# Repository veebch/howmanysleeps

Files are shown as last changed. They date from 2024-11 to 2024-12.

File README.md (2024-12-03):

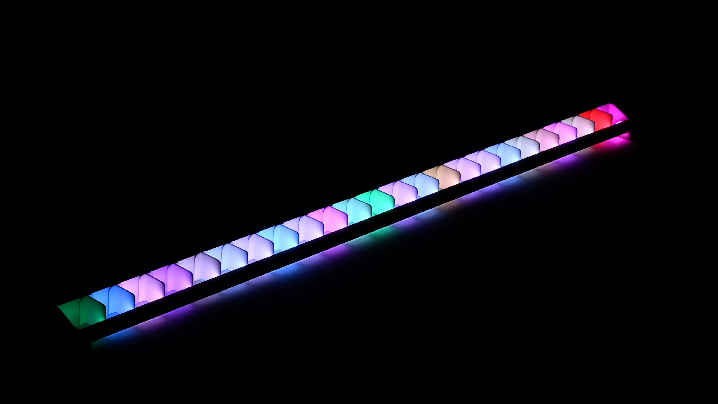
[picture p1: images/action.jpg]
Action Shot


 

# How Many Sleeps?

An Advent Calendar progress-bar decoration that uses a Raspberry Pi Pico W (2) to show you how many sleeps until Christmas (during Advent). It has
a light dependent resistor (LDR) to make the lights only turn on when it is dark and an override button so that you can turn 
the lights off at bedtime. 

Outside of advent, it acts as an automatic light, which is also pretty.

## Assembly

### Components

#### Electronics 

- Rasperry Pi Pico 2W (it is compatible with the original W too)
- 1m 144 LED neopixel strip (We used a WS2812 B Eco)
- Momentary Switch
- Light Dependent Resistor (LDR)

#### Enclosure
 
- Prototype board
- 1m L shaped metal strip
- 1m wooden strip (rectangular cross section) 
- 23 separator fins and two end pieces (all in [/3d](3d) directory)

## Build Video

A whizz through the build process:

YouTube (https://www.youtube.com/watch?v=zQKZN75o05Y)

## Wiring

The LDR and the momentary switch both go to GND from GPIO 26 and 15 respectively. 
The NeoPixel strip is connected to GPIO 19 (as well as VSYS and GND)

## Software

Copy the file main.py onto your Pico using whatever method you find easiest. For this single file, it is probably quickest just to use Thonny. Put your WiFi details into the code and that should be it!

## Operation

At dusk (the LDR value can be adjusted in the code if needed) the lights turn on. If it is currently Advent, then the bar acts as a progress bar, charting the number of sleeps until Christmas.
Outside of advent, the light will be a 'breathing' pattern.

Pressing the momentary switch will disable the lights until it gets light again. When it gets bright again, the Pico will reset.

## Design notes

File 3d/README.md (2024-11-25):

# Light Separators

For the 144 LED strip, you will need to print 23 of these to stop ligth leak between days (6 LEDs each)

# End pieces

These may need to be adjusted based on your metal and wood strips

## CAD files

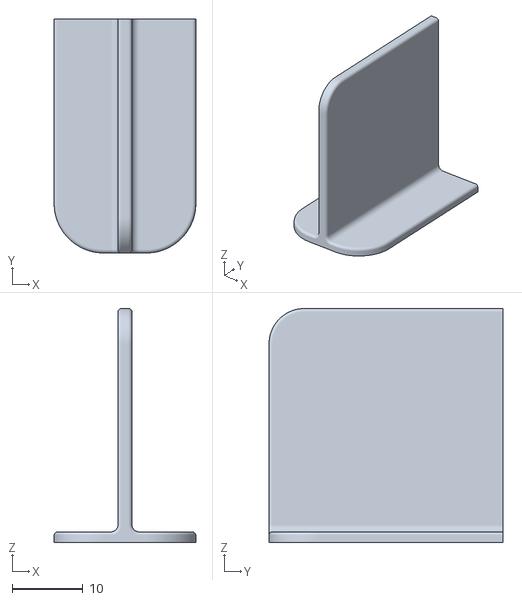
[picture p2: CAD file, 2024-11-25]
3d/barlink.stl
20.0 x 33.0 x 33.0

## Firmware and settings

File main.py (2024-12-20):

import network
import urequests
import time
from machine import Pin, ADC, reset
import neopixel
import random
import math

# Globals
# WiFi credentials
SSID = 'whyayefi'
PASSWORD = 'dizzyflower278'
PIXELS = 144

# Pin Assignment
ldr = ADC(26)  # LDR connected to ADC on GPIO 26
switch = Pin(15, Pin.IN, Pin.PULL_UP)  # Pull-up for momentary switch
np = neopixel.NeoPixel(Pin(19), PIXELS)
led = Pin("LED", Pin.OUT)


def trigger_bedtime(pin):
    global bedtime, np
    switch.irq(handler=None)  # Disable the interrupt after the first trigger we want the button to work once only per day
    print("Interrupt disabled")
    bedtime = True
    print('lights out')


# Function to connect to WiFi
def connect_to_wifi(ssid, password):
    wlan = network.WLAN(network.STA_IF)
    wlan.active(True)
    wlan.connect(ssid, password)
    while not wlan.isconnected():
        print("Connecting to WiFi...")
        time.sleep(1)
    print("Connected to WiFi:", wlan.ifconfig())


# Function to get timezone using ip-api.com
def get_timezone():
    url = "http://ipwhois.app/json/"
    try:
        print("Fetching timezone from IP...")
        response = urequests.get(url)
        if response.status_code == 200:
            data = response.json()
            timezone = data.get('timezone', None)
            response.close()
            if timezone:
                print(f"Detected timezone: {timezone}")
                return timezone
            else:
                print("Timezone not found in response.")
                return None
        else:
            print(f"Error fetching timezone: {response.status_code}")
            response.close()
            return None
    except Exception as e:
        print("Error retrieving timezone:", e)
        return None

# Function to get local time using timeapi.io
def get_local_time(timezone):
    url = f"https://timeapi.io/api/Time/current/zone?timeZone={timezone}"
    try:
        print(f"Fetching local time for timezone: {timezone}")
        response = urequests.get(url)
        if response.status_code == 200:
            data = response.json()
            # Extract year, month, day directly from the JSON response
            year = data['year']
            month = data['month']
            day = data['day']
            response.close()
            return (year, month, day)
        else:
            print(f"Error fetching local time: {response.status_code}")
            response.close()
            return None
    except Exception as e:
        print("Error retrieving local time:", e)
        return None



# Calculate sleeps until Christmas
def sleeps_until_christmas(current_date):
    current_year = current_date[0]
    christmas_date = (current_year, 12, 25)
    christmas_struct = time.mktime(christmas_date + (0, 0, 0, 0, 0))
    today_struct = time.mktime(current_date + (0, 0, 0, 0, 0))
    sleeps = (christmas_struct - today_struct) // 86400 # seconds in a day
    return int(sleeps)


def clamp(value, min_val=0, max_val=255):
    # Clamp a value between min_val and max_val.
    return max(min(int(value), max_val), min_val)

def progress(np,sleeps, spread, howdark):
    advent = sleeps <= 24
    brightfactor=min(int(255*400/(2*(howdark+1))),255)
    print(brightfactor)
    if advent:
        # Advent adjustment to progress bar
        # to make things confusing, LEDs are indexed from (PIXELS-1) to 0
        for i in range(24, sleeps-1, -1):
                variation_1 = (25-i) * random.choice ([-1,1]) #either -1 or +1, each sleep less is more volatile
                variation_2 = (25-i) * random.choice ([-1,1])
                pixelblockchunk = int(PIXELS/24) # We'll use blocks of this size for the first 23 days
                pixelblockmax = PIXELS - (24 - i) * pixelblockchunk
                if i>1:
                    pixelblockmin = pixelblockmax - pixelblockchunk
                else:
                    pixelblockmin = 0
                    # For Christmas Eve, use all remaining pixels
                #print(f'Day: {i}. {pixelblockmin} to {pixelblockmax}')
                for j in range(pixelblockmin,pixelblockmax):
                # Each block drifts at random, clamped between 0 and 255
                    r, g, b = np[j]  # The current RGB values of the pixel
                    r = clamp(r + variation_1,0,brightfactor)
                    g = clamp(g - variation_1,0,brightfactor)
                    b = clamp(int(500/(howdark+1)*(b + variation_2)),0,brightfactor)
                    
                    
                    np[j] = (r,g,b) 
    else:
        for i in range(PIXELS):
            # If it is not advent, then this formula will give a nice 'breathing' effect
            brightness = 32 * (1 + 4 *(math.sin(spread + math.pi)+1)) * math.exp(-(PIXELS/2-i) ** 2 / (1+20*(math.sin(spread)+1)) ** 2)
            np[i] =  ( clamp(brightness), clamp(.40*brightness), clamp(.15*brightness))
    np.write()


def lightsout(np):
    for i in range(PIXELS):
        np[i] =  (0,0,0)
    np.write()


# Main program
def main():
    global bedtime

    # Initialise local variables
    LDR_THRESHOLD = 200 # The light dependent resistor reading threshold for light/dark
    CONSECUTIVE_COUNT = 250 # Consecutive readings needed to count a reading as 'consistent
    consecutive_light_count = 0  # Counter for consecutive light readings below the threshold
    consecutive_dark_count = 0  # Counter for consecutive light readings below the threshold
    consistent_light = False
    consistent_dark = False
    spread = 0
    dark = False # Assume light
    bedtime = False  # Bedtime button not pressed
    twopi = math.pi*2

    # Interrupts
    switch.irq(trigger=Pin.IRQ_FALLING, handler=trigger_bedtime)

    # Start
    # toggle onboard LED as sign of life
    led.on()       		# Turn the LED on
    time.sleep(0.5)     # Keep it on for 0.5 seconds
    led.off()      		# Turn the LED off
    lightsout(np) 		# Turn off the light strip lights
    connect_to_wifi(SSID, PASSWORD)
    # Get local time directly using IP

    # Get timezone from IP
    timezone = get_timezone()
    if timezone is None:
        print("Could not detect timezone.")
        return

    # Get local time using the detected timezone
    current_date = get_local_time(timezone)
    if current_date is None:
        print("Could not retrieve local time.")
        return

    print(f"Current local date: {current_date}")

    # Calculate sleeps until Christmas
    sleeps = sleeps_until_christmas(current_date)
    print(f"Number of sleeps until Christmas: {sleeps}")
    # sleeps = 1
    # Main Loop
    while True:
        spread = (spread +.05) % twopi # The parameter that gets passed to progress for periodic light
        howdark = ldr.read_u16()
        dark = howdark > LDR_THRESHOLD # True if ldr value is read as high
        if consistent_dark and not bedtime:  # Darkness detected
            progress(np,sleeps,spread,howdark)
        else:
            if bedtime or consistent_light:
                lightsout(np)

        if consistent_light and bedtime:
            # It has been light for multiple consecutive readings following a bedtime button press
            print('Looks like morning. Resetting...')
            reset()

        if dark:
            consecutive_light_count = 0  # Reset counter if reading goes above threshold
            consecutive_dark_count += 1
        else:
            consecutive_light_count += 1
            consecutive_dark_count = 0
        consistent_dark = consecutive_dark_count >= CONSECUTIVE_COUNT
        consistent_light = consecutive_light_count >= CONSECUTIVE_COUNT




# Run the main program
if __name__ == "__main__":
    main()
